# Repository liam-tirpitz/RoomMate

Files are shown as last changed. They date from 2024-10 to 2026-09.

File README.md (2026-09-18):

# RoomMate

RoomMate provides digital e-ink signs for bookable resources such as meeting rooms and offices (OfficeMate).
For meeting rooms, your RoomMate displays the current availability (occupied / available), as well as a list of upcoming meetings.
OfficeMates display up to two names and affiliations, as well as potential out-of-office notices.
This project was developed for the infrastructure at RWTH Aachen University, but is configurable to other scenarios.

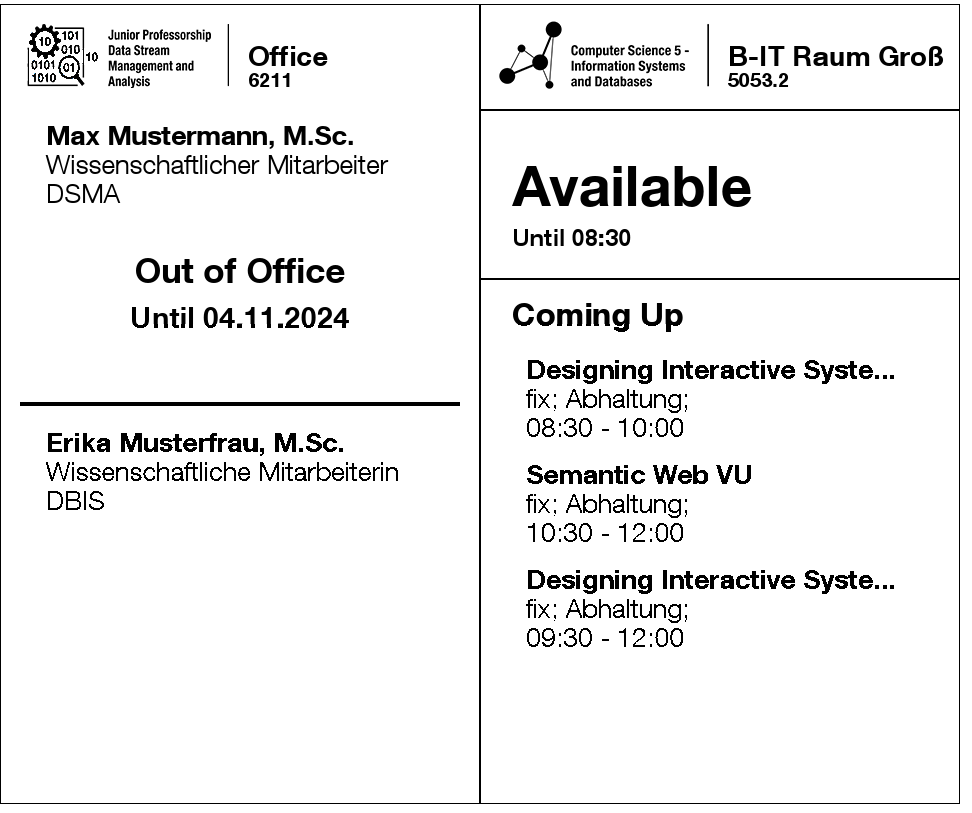
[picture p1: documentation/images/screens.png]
Screens


We currently support room calendars accessible through Microsoft Exchange and published as ical via RWTHOnline.
The calendar information is accessed through a nodejs server component.
The client consists of an eink screen and an esp32 board.
The screen content is processed on the server.
The client regularly requests the server via WiFi and HTTP and updates the screen content.

## Usage
If configured accordingly, the RoomMates for bookable rooms will automatically display the current and upcoming room occupations.
The end users can influence the content by booking the associated resources via Outlook (or RWTH Online).
The displays are battery operated.
If the battery is low and needs to be recharged, the screen will not update anymore and show a low battery warning.
In that case, the RoomMate needs to be charged via the USB-C port.

OfficeMates can be configured by the occupants of that office via their personal calendars.
Please find the details on the necessary configuration below.
If configured accordingly, Out of Office notices are automatically generated if the primary calendar of the associated user in Exchange 
contains a current appointment with  "Show as" set to "Out of Office".
The system will automatically determine the duration and display it as well.

Additionally, the occupants can configure a separate calendar "SIGN" to display custom messages.
If a custom message is set, it overwrites a potential out of office notice from the primary calendar.
For entries in "SIGN", users can set a title and the body of the message.
The message is displayed for the set duration of the appointment.
The location field is ignored.
The first 5 lines of the message body are displayed.
The title should only use 25 characters and each body line should not be longer than 45 characters.
Do not use additional HTML formatting or your message may be displayed wrong.

### Exchange Calendar Setup
If calendars are retrieved from Exchange, the system user used to access the calendars in a domain needs the permission to do so.
For different types of screens, different permissions need to be set.

#### Bookable Room Calendar
For rooms and resources, the system user needs read access to the "Full Calendar Details" (Reviewer).
These permissions can be configured by the room manager via the calendar properties in Outlook.

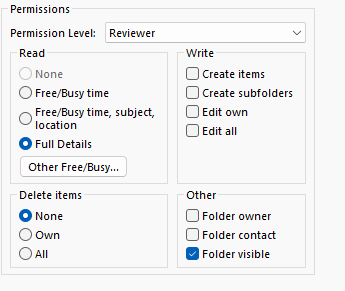
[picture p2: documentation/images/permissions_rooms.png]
Permissions


#### Personal Availability
In the case of offices, each occupant can configure their access individually.
To display Out of Office notices, the system user needs read access to the Free/Busy times.
This is often already set as the Default permission for users in the same domain, so it may not be necessary to set this explicitly.

To display custom messages, a separate calendar needs to be created and named "SIGN".
The system user needs read access to the "Full Calendar Details" (Reviewer) of the "SIGN" calendar.
Additionally, to find this calendar, the system user needs access to "Folder visible" __of the primary (parent) calendar__.

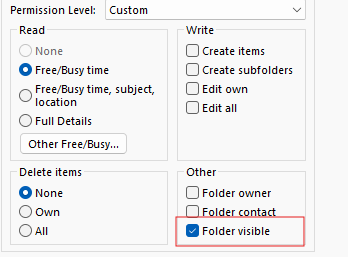
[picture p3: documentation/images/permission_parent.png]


Please note that the display of availability and out of office messages is optional. 
If the necessary permissions are not set, the display will function as a static room sign.

## Server Deployment
For an easy deployment of the server component, we recommend using our Docker image.
You can find an example on a possible docker-compose setup with that image in our [Deployment Examples](server/room-manager/deployment_example).
You can download the example and start the server with `docker compose up -d` after you changed the configuration for your needs.
The image is published as `ghcr.io/liam-tirpitz/roommate/room-manager` (`latest` for releases, `nightly` for the development branch).
The examples mount the whole [config](server/room-manager/deployment_example/config) directory, which contains `calendars.json` and the logos, to `/home/node/app/room-manager/config`, and the logs to `/home/node/app/room-manager/logs`.
Secrets can be placed in an optional `.env` file next to the `file` and `mongo` folders.

Alternatively, you can clone the repository, install node and start the server with

```bash
npm i
npm run build
npm run start
```
Make sure to pass a correct configuration and secrets.
The following environment variables are recognized:
```STORAGE``` can either be set to ```MONGO``` or ```FILE``` (default).
This determines if a MongoDB instance is expected as the storage backend or if a JSON configuration file is used.
Please note, that we currently do not support changing data via the API for the File-Backend. Write requests answer `501`.

```API_TOKEN``` enables the management API (`/rooms`, `/devices`, `/ewsusers`, `/organization`).
Requests must send it as `Authorization: Bearer <token>`.
Without it, the management API answers `403`.
The device endpoints `/data` and `/image` are always open, because devices can't authenticate.
Even with a token, only expose port 3001 to the network your devices use.
For details, please check out the [Deployment Examples](server/room-manager/deployment_example).

## Server Configuration
If a file backend is chosen, the configuration of all the rooms, persons, devices and endpoints can be done with the [calendars.json](server/room-manager/deployment_example/config/calendars.json).
For development purposes, this file should be placed inside a config directory in the root of the project.
The configuration file is loaded once when the project is started. 
If the configuration is changed, the server needs to be restarted.

### Global Configuration
`global_config` holds the settings that apply to all signs:
- `soon_threshold_in_min`: how long before a meeting a room sign shows "Next Meeting – Starts soon".
- `night_start_hour` and `night_end_hour`: signs don't update at night and wake up again at `night_end_hour`.
- `timezone`: the timezone used for all times on the signs, e.g. `Europe/Berlin`.
- `low_battery_voltage_cutoff_in_mv`: below this battery voltage, room signs show the low battery screen.
  Below 3100 mV the firmware fetches the screen one last time and then stops updating until it is charged.
  Keep this value at or above 3100 mV. Otherwise that last screen is a normal one, and the sign keeps showing outdated content without a warning.
- `default_logo`: the logo from the config directory shown on signs that are not associated with a room yet.

### Room and Device Configuration
Each room is configured with a `name` and an `id_string`, which are displayed on the screen.
In addition the affiliation of the room can be shown by using a custom logo from the config directory, indicated via `logo`.
The type of calendar is defined by either defining `ews_info` OR `ical_info` (see below).
Each device consists of a `device_id` (MAC-Address) and a descriptive `location` string.
Rooms are directly associated with the device they are configured for.
If the same room has multiple displays, the room configuration needs to be duplicated.

```json
"devices": [
    {
        "device_id": "aaaaaaaaaaaa",
        "location": "Left_Door",
        "room_id": {
            "room_number": 200,
            "id_string": "200a",
            "name": "Meetingraum",
            "logo": "institute_logo.png",
            "ews_info": {
                "email": "room@domain",
                "tenant_id": 1
            }
        }
    }
]
```

### Office Configuration
In case of offices, at most two people can be defined with independent (Exchange) calendars.
The definition of people can be set instead of an `ews_info` or `ical_info`.
Each person has a `name`, a `job` and a `group`. 
This data is displayed on the screen.
Additionally, each person has an independent `email` and `tenant_id` to retrieve their data through EWS.

```json
"persons": [
    {
        "name": "Max Mustermann, M.Sc.",
        "job": "Wissenschaftlicher Mitarbeiter",
        "group": "DSMA",
        "ews_info": {
            "email": "mustermann@institute.rwth-aachen.de",
            "tenant_id": 1
        }
    }
]
```

### Calendar Configuration
Currently, we can retrieve data from either an Exchange Server, or via ical files.

#### Exchange Configuration
To access data through the Exchange Web Services API (EWS), which is required for rooms, resources and users available in Outlook,
we need to configure access for each exchange domain.
Specifically, we need an endpoint and credentials for a user with the necessary permissions.
This user needs permissions to read the calendars for all entities that we want to map to a display.
Multiple credentials can be stored for users across domains or exchange infrastructures (`tenants`).

```json
"exchange": {
    "tenants": [
      {
        "identifier": 1,
        "endpoint": "https://ENDPOINT/EWS/Exchange.asmx",
        "user": "USER@DOMAIN",
        "secret": "SECRET"
      }
    ]
}
```

The users can then be mapped to each calendar.
Each exchange tenant requires an `endpoint`, a `user` and a password.
Through the `identifier`, exchange credentials can be mapped to a specific room or person (`tenant_id`).
The username of each calendar retrieved through exchange is configured as part of the individual calendar configuration as `email`.
```json
"calendars": [
  {
    ...
    "ews_info": {
      "email": "room@domain",
      "tenant_id": 1
    }
    
  }
]
```

We configure the endpoint and the username in the configuration file.
The passwords are injected at runtime through environment variables (`secret`).

##### Secrets
The configuration key `exchange.tenants.secret` defines the _name_ of the environment variable that is injected.

There are 3 supported ways  to inject the secrets.
First, if a Docker deployment is used is used, 
the secrets can be passed directly to the container, via the [docker-compose.yml](server/room-manager/deployment_example/file/docker-compose.yml).
For development purposes, the variables can be defined in a .env file placed in [server/](server).

Lastly, the secrets can be synchronized via [Bitwarden Secrets Manager](https://bitwarden.com/products/secrets-manager/).
In that case, we need to configure an access token in BWS and configure the environment variable `BWS_ACCESS_TOKEN`.
For this to work locally, you need to install the [Secrets Manager CLI](https://bitwarden.com/help/secrets-manager-cli/).
Local injection via the Secrets Manager can be enabled by using `npm run start_bws` or `npm run dev_bws`
The docker image already contains the CLI tool. 
To enable it, pass the `BWS_ACCESS_TOKEN` environment variable.
If this variable is not present, the secrets should be passed directly via environment variables.

#### ICal Configuration
The ical module only requires a public HTTP endpoint from which the calendar is retrieved.
__Please note, that the current ical implementation is incomplete.__
Calendars from RWTHOnline can be parsed, but more complex structures (especially recurrences) are not yet supported.

```json

"calendars": [
  {
    ...
    "ical_info": {
      "endpoint": "www.domain.de/calendar"
    }
    
  }
]
```
### Logos
We can define different logos for each device.
These logos should be placed alongside the configuration file in the config directory.
These images should be in png format and ideally already black and white. 
If they are colored, the image processing will make them black and white, but this may be less beautiful.
For the correct resolution, please check the [example](server/room-manager/deployment_example/config/institute_logo.png).

## Client

### Hardware
The hardware of the RoomMates consists of a 3D printed case and the electronics.

#### Electronics

The electronics of the RoomMates consist of the following components:
For details, see the [Bill of Material](./hardware/bom.xlsx)

- EInk-Display (7.5 inch, 800x400 black/white module with driver HAT [from Waveshare](https://www.waveshare.com/7.5inch-e-paper-hat.htm))
- ESP32-Microcontroller Development Board ([Adafruit ESP32 Feather V2](https://www.adafruit.com/product/5400))
- 3700 mAh LiPo Battery

The driver HAT connects the E-Ink display to the Microcontroller.
The Feather has built-in LiPo support and directly connects to the battery.
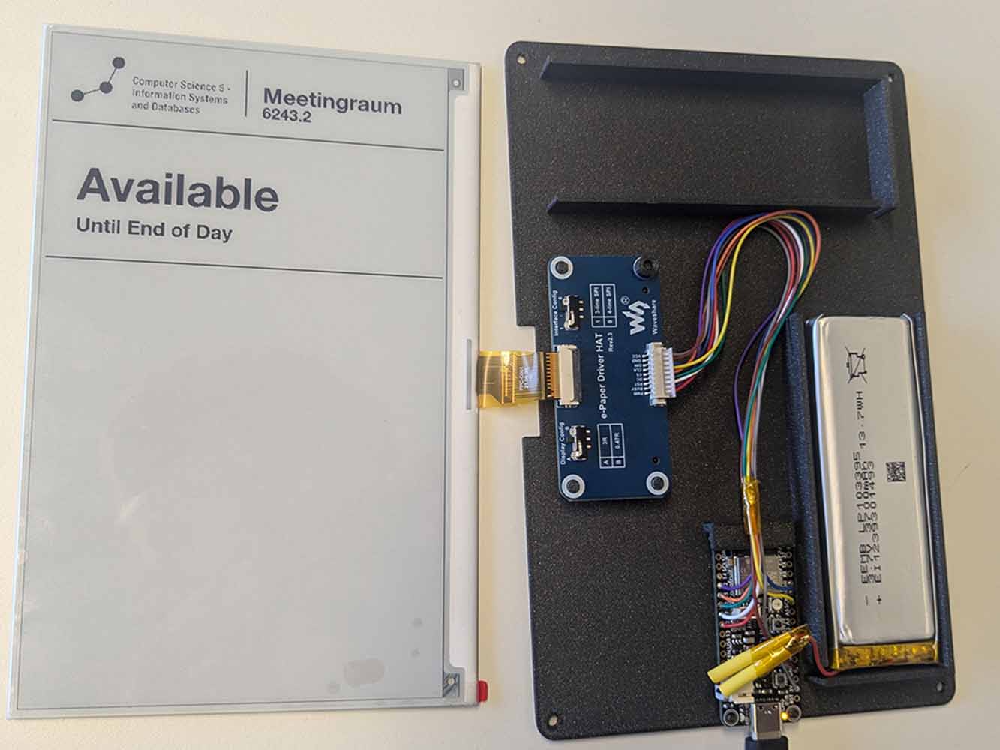
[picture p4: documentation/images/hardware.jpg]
Hardware Wiring


#### Wiring 
The e-ink HAT connector cable need to be soldered to the Feather board, according to the following pinout.
The used pins are defined in [DEV_Config.h](./client/room-occupancy/Room-Occupancy-Client/lib/esp32-waveshare-epd/src/DEV_Config.h)

| E-Ink | Feather |
|---|---|
| PWR | 12 |
| BUSY  | 32 |
| RST | 27 |
| DC | 33 |
| CS | 15 |
| CLK | 5 (SCK) |
| DIN | 19 (MOSI) |
| GND | GND |
| VCC | 3V |

#### Case
The case consists of three parts.
The front cover holds and exposes the eink display, the middle part holds the electronics and the battery and
the backplate holds everything in place and provides mounting holes for hanging the device.
The case was designed in Fusion 360.
We provide the [Fusion project files](./hardware/case/fusion_project_files) and exported [STEP files](./hardware/case/step-files).
In our deployment, we print the case on a Prusa MK4 3D printer with [Prusament PLA in Galaxy Black](https://www.prusa3d.com/de/produkt/prusament-pla-prusa-galaxy-black-1kg/).

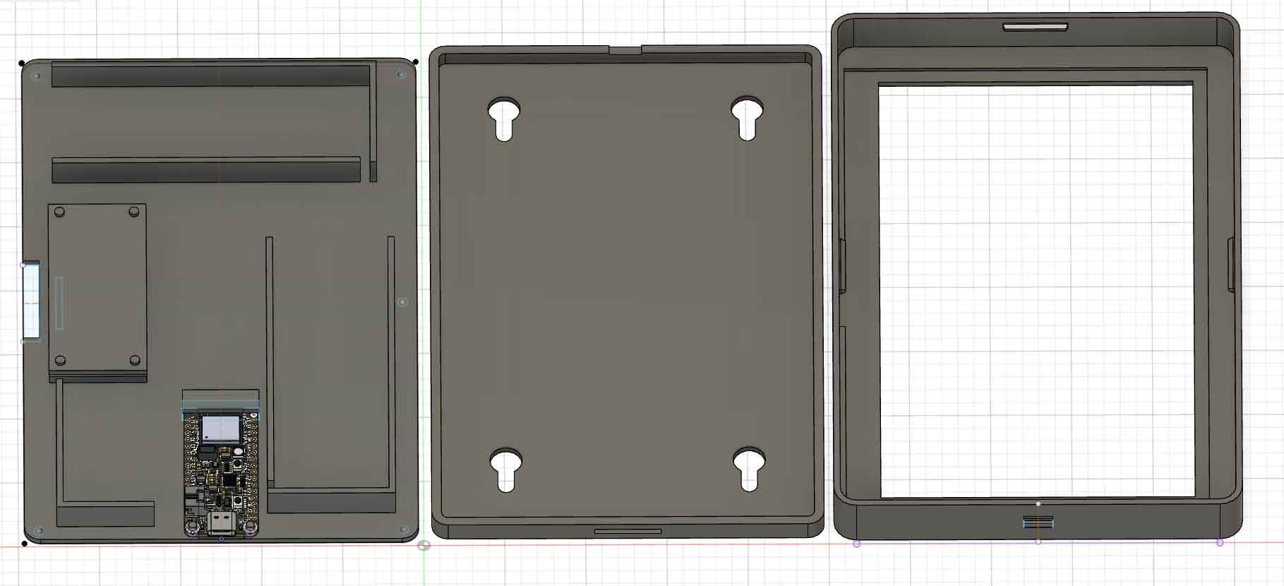
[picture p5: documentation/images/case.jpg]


### Software
The client software project is developed with [PlatformIO](https://platformio.org/) as the IDE.
The firmware of devices can be flashed via USB.

### Provisioning
To communicate with the server, each RoomMate must be provisioned with WiFi credentials and the server endpoint.
With the Provisioner [Gordon tool](server/room-manager/src/provisioner/gordon.ts) devices can be automatically provisioned, using credentials stored in the Bitwarden Secrets Manager.
For a device with the MAC address "aa:aa:aa:aa:aa:aa", place a secret of the form `PSK_aaaaaaaaaaaa` in the store.
Set `GORDON_SSID` and `GORDON_ENDPOINT` (for example `http://your-server.example.com:3001/`), run `npm run dev_gordon` and connect the RoomMates via USB.
Gordon only talks to Feather ESP32 V2 boards (USB ID `1a86:55d4`) that answer `wifi.getMAC` with a MAC address.
It provisions each connected device once and provisions it again only after it was unplugged.

Alternatively, you can manually use the the CLI via serial at a baud rate of 115200.
The following commands are needed to provision the device.

```bash
wifi.getMAC
wifi.setCredentials SSID PSK
config.setEndpoint http://SERVER:PORT/
restart
```

`config.setEndpoint` adds a missing trailing slash.
`config.setSleepInterval SECONDS` optionally changes the regular wakeup interval; it accepts values from 60 to 86400 seconds.

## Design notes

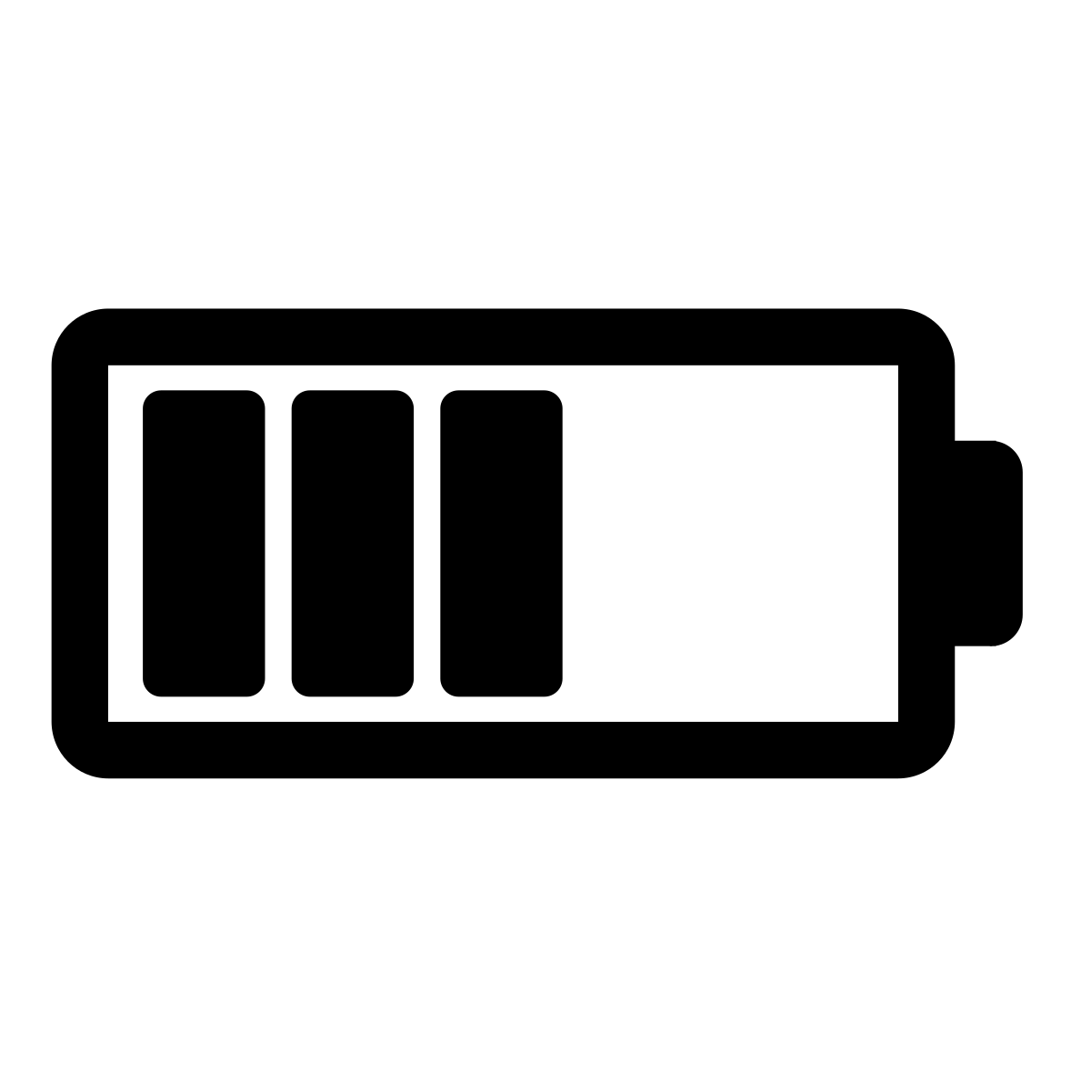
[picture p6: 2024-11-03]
server/room-manager/src/image_processing/assets/battery_3.png

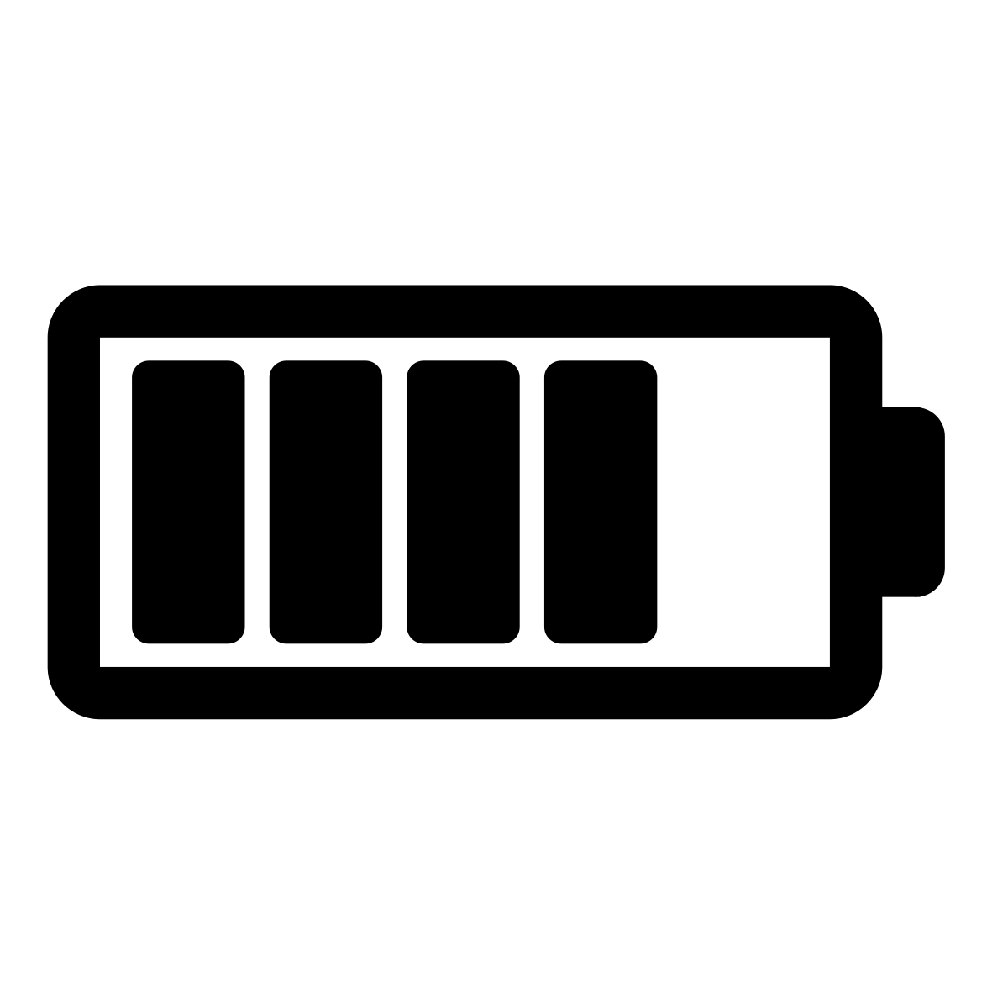
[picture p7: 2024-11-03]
server/room-manager/src/image_processing/assets/battery_4.png

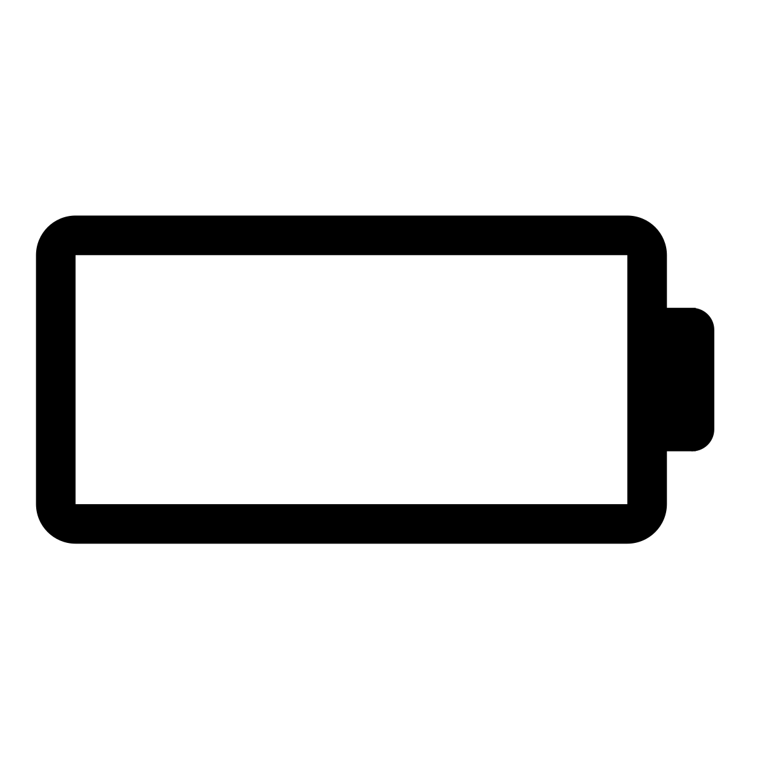
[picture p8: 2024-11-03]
server/room-manager/src/image_processing/assets/battery_0.png

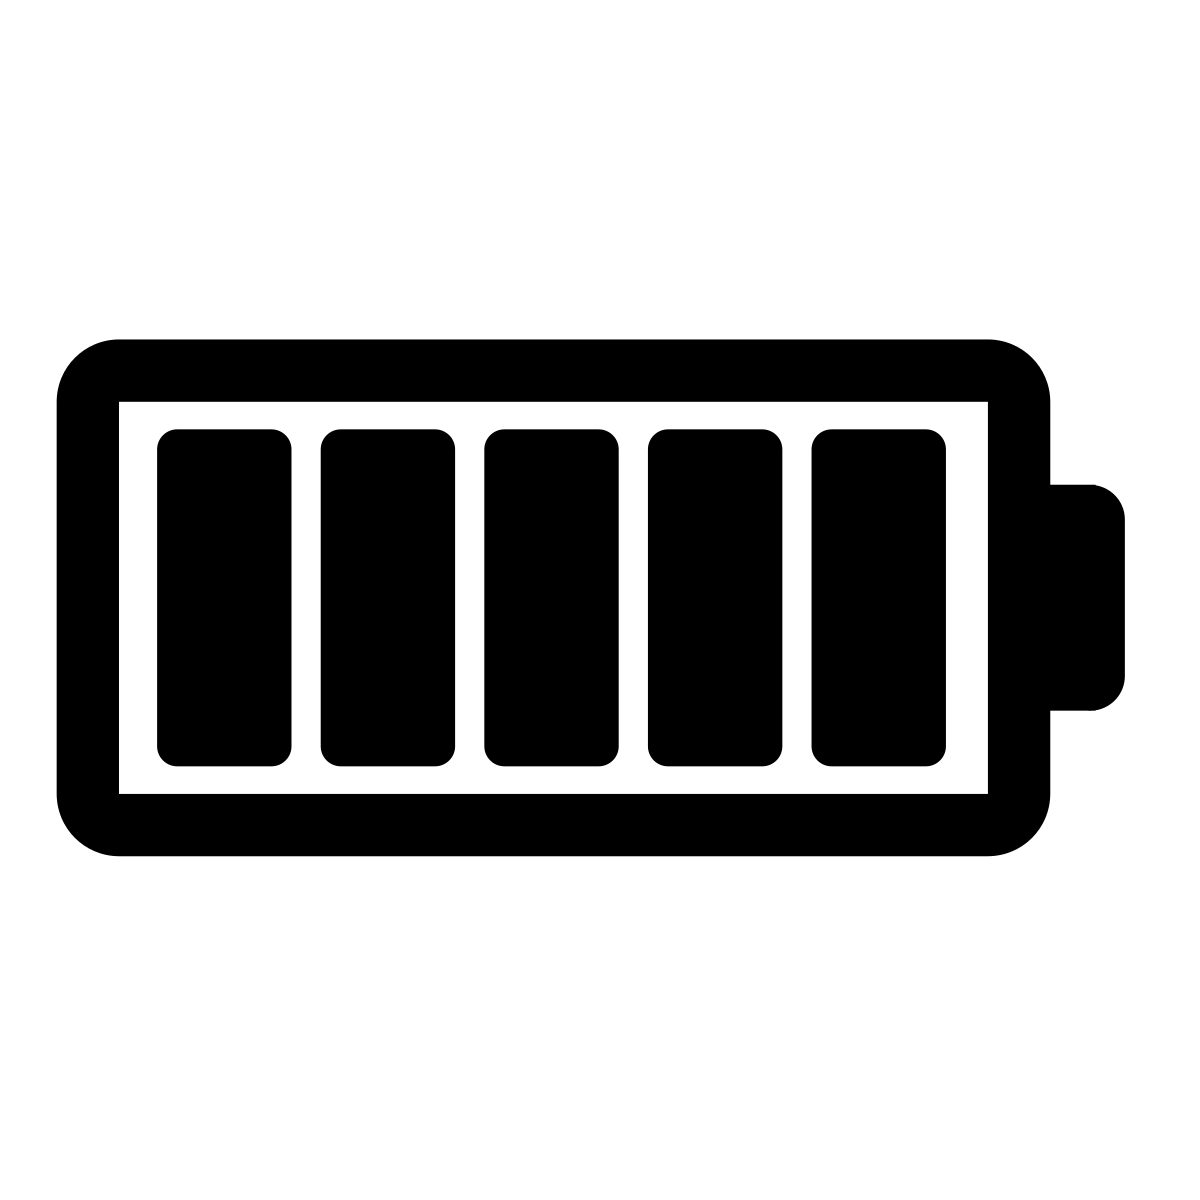
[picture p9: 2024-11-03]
server/room-manager/src/image_processing/assets/battery_5.png

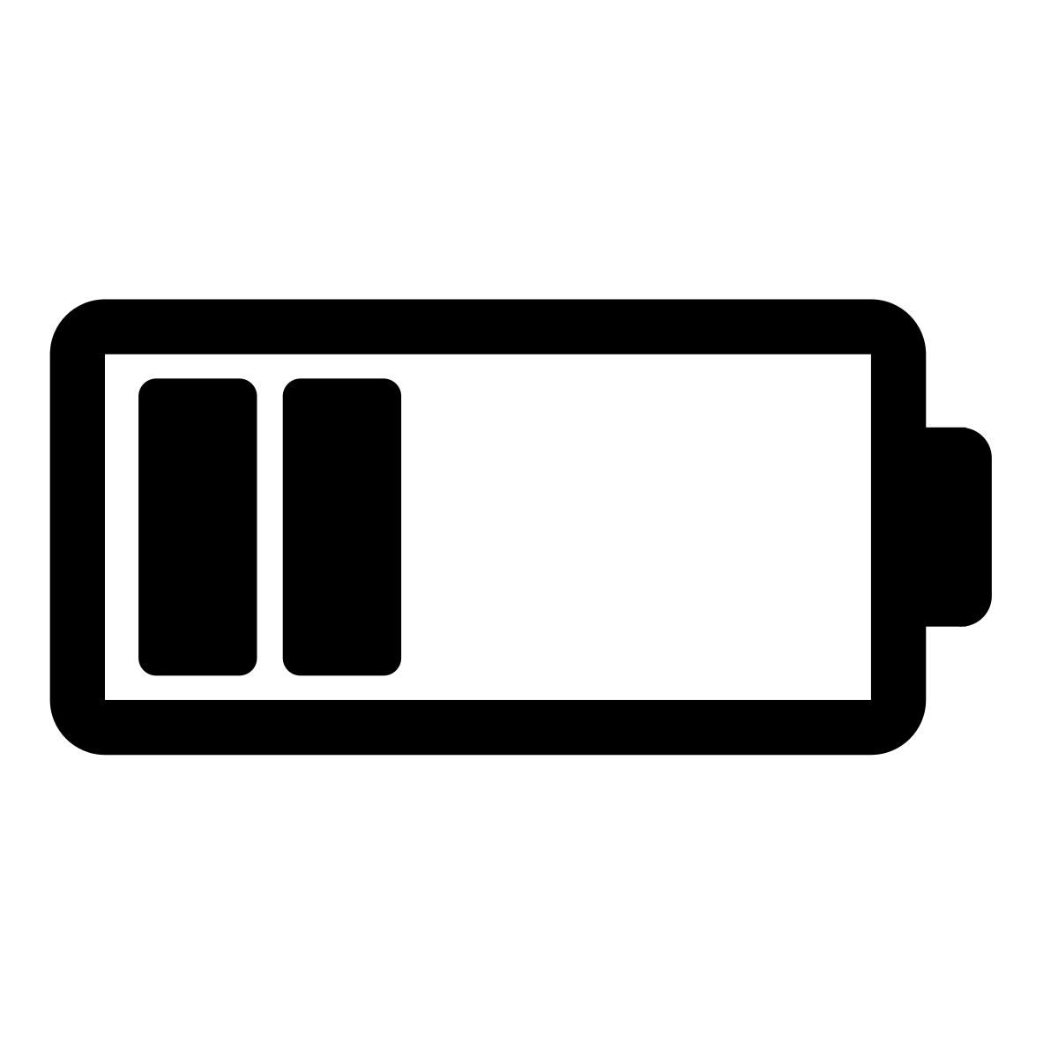
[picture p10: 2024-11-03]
server/room-manager/src/image_processing/assets/battery_2.png

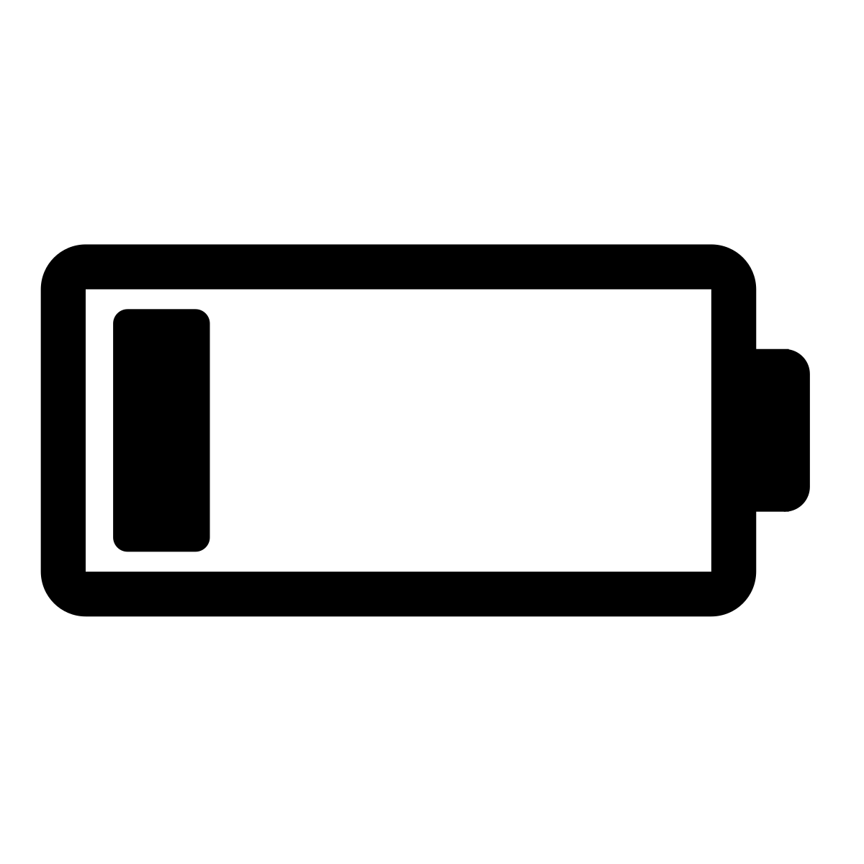
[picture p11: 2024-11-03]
server/room-manager/src/image_processing/assets/battery_1.png

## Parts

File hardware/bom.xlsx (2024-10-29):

Was |  | Preis | Stk | Kosten
EEMB LiPo 3700 mA | Akku | 13 | 2 | 26 | https://www.amazon.de/dp/B08215B4KK?ref=ppx_yo2ov_dt_b_fed_asin_title
Adafruit Feather V2 | uC | 20.3 | 1 | 20.3 | https://www.berrybase.de/adafruit-esp32-feather-v2
Waveshare 7.5 mit HAT v2 | eInk Panel | 56.9 | 1 | 56.9 | https://www.berrybase.de/7.5-800-480-epaper-display-hat-fuer-raspberry-pi-v2
 |  |  | KOSTEN | 103.2

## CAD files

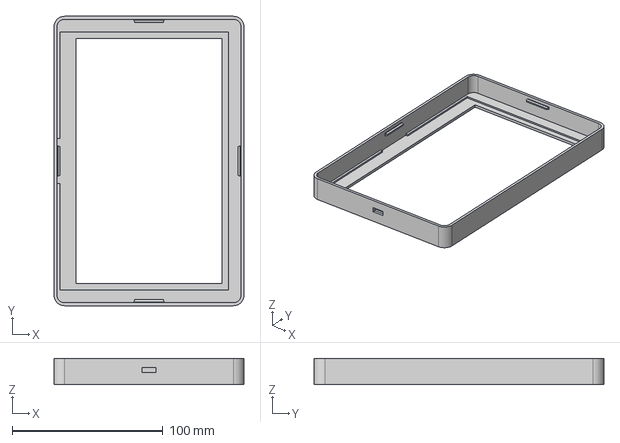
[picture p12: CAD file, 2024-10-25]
hardware/case/step-files/Front+Cover_small.stp
126.0 x 192.0 x 17.5 mm

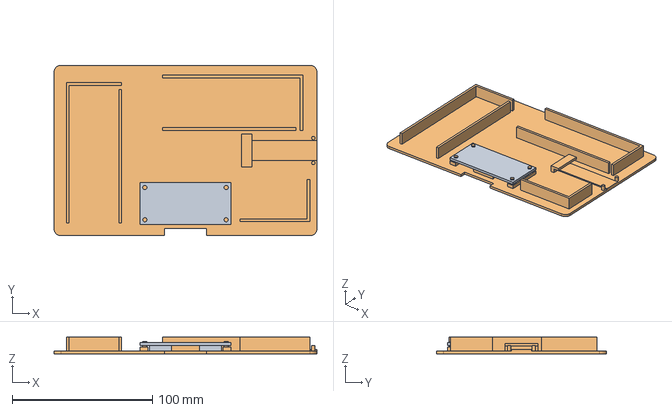
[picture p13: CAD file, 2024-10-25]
hardware/case/step-files/Gehaeuse+Mittelebene+small+feather.stp
187.5 x 121.5 x 12.0 mm

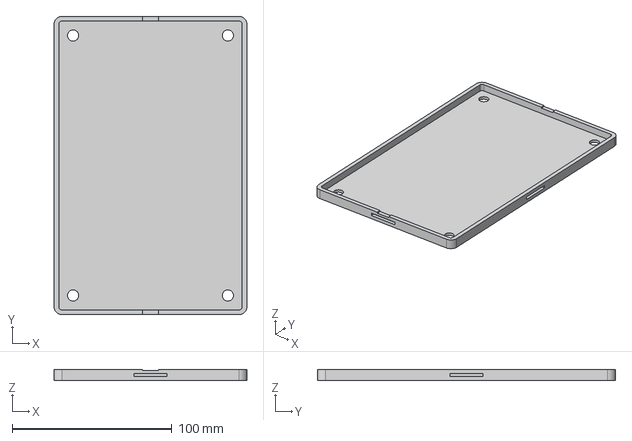
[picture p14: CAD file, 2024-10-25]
hardware/case/step-files/Backcover+small.stp
121.0 x 187.0 x 7.00 mm

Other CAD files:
hardware/case/fusion_project_files/Backcover+small.f3d
hardware/case/fusion_project_files/Front+Cover_small.f3z
hardware/case/fusion_project_files/Gehaeuse+Mittelebene+small+feather.f3z

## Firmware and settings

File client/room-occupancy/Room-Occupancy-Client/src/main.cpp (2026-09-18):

/*
 *  This sketch sends a message to a TCP server
 *
 */
#include <Arduino.h>
#include <HTTPClient.h>
#include <ArduinoJson.h>
#include <Screen.h>
#include "mbedtls/base64.h"
#include <Provisioner.h>
#include <Storage.h>
#include <SysConfig.h>
#include <ETH.h>

#define IMAGE_BUFFER_SIZE 48000
#define IMAGE_DOWNLOAD_TIMEOUT_MS 30000
// Below this voltage the radio is kept off, above the second one normal operation resumes.
// The cutoff must not be higher than low_battery_voltage_cutoff_in_mv on the server, otherwise the
// server still renders a normal screen while the device already stops updating.
#define LOW_BATTERY_CUTOFF_IN_MV 3100
#define LOW_BATTERY_RECOVERY_IN_MV 3300
#define LOW_BATTERY_SLEEP_IN_S 3600
// Time the device stays awake for serial provisioning before it goes to sleep
#define PROVISIONING_TIMEOUT_MS 600000
#define UNPROVISIONED_SLEEP_IN_S 3600
// Stored instead of a server hash while the server answers 404 for this device
#define UNKNOWN_DEVICE_HASH "unknown-device"

unsigned char b64_buff[800] = {0};
unsigned char byte_buff[IMAGE_BUFFER_SIZE] = {0};

bool eth_connection_established = false;
bool unprovisioned = false;

String devid = "";
int voltage = 0;
JsonDocument doc;


FooterState footerState;
Screen screen {&footerState};

Storage storage;
SysConfig sysconfig;


uint8_t getImageDataFromEndpoint() {
    #ifdef ARDUINO_ADAFRUIT_FEATHER_ESP32_V2
      if(WiFi.status() == WL_CONNECTED){
    #else
      if(true) {
    #endif
      HTTPClient http;
      
      String endpoint = storage.getEndpoint() + "image?devid=" + devid;
      #ifdef ARDUINO_ADAFRUIT_FEATHER_ESP32_V2
      endpoint += "&voltage=" + String(voltage);
      #endif


      http.begin(endpoint);

      int httpResponseCode = http.GET();
      size_t buffer_offset = 0;
      if (httpResponseCode>0) {
        if (httpResponseCode == HTTP_CODE_OK) {
            int len = http.getSize();
            WiFiClient *stream = http.getStreamPtr();
            // Base64 can only be decoded in complete 4-character groups, but the stream
            // delivers arbitrary chunk sizes. Up to 3 leftover characters are carried
            // over to the front of b64_buff and decoded together with the next chunk.
            size_t carry = 0;
            bool decode_failed = false;
            unsigned long download_start = millis();
            while (http.connected() && (len > 0 || len == -1)) {
              if (millis() - download_start > IMAGE_DOWNLOAD_TIMEOUT_MS) {
                printf("Image download timed out\n");
                decode_failed = true;
                break;
              }
              size_t size = stream->available();
              if (size) {
                size_t space = sizeof(b64_buff) - carry;
                int c = stream->readBytes(b64_buff + carry, (size > space) ? space : size);
                if (len > 0) {
                  len -= c;
                }
                size_t available_chars = carry + c;
                size_t decodable_chars = available_chars - (available_chars % 4);
                if (decodable_chars > 0) {
                  size_t outlen = 0;
                  int decode = mbedtls_base64_decode(byte_buff + buffer_offset, IMAGE_BUFFER_SIZE - buffer_offset,
                                                     &outlen, b64_buff, decodable_chars);
                  if (decode != 0) {
                    printf("Base64 decode failed: %d at offset %u\n", decode, (unsigned) buffer_offset);
                    decode_failed = true;
                    break;
                  }
                  buffer_offset += outlen;
                }
                carry = available_chars - decodable_chars;
                memmove(b64_buff, b64_buff + decodable_chars, carry);
              } else {
                delay(1);
              }
            }

          http.end();
          if (decode_failed || carry != 0 || buffer_offset != IMAGE_BUFFER_SIZE) {
            printf("Incomplete image: %u of %d bytes\n", (unsigned) buffer_offset, IMAGE_BUFFER_SIZE);
            return 4;
          }
          return 0;
        }
      }
      else {
        // Serial.print("Error code: ");
        // Serial.println(httpResponseCode);
        http.end();
        return 1;
      }
      // Free resources
    }
    else {
      printf("WiFi Disconnected\n");
      return 2;
    }
    return 3;
}

bool getMetaDataFromEndpoint() {
  bool success = false;
  #ifdef ARDUINO_ADAFRUIT_FEATHER_ESP32_V2
  if(WiFi.status() == WL_CONNECTED){
  #else
  if(true) {
  #endif
    HTTPClient http;
    http.begin(storage.getEndpoint() + "data?devid=" + devid);
    printf("BEGIN\n");
    int httpResponseCode = http.GET();
    if (httpResponseCode>0) {
      if (httpResponseCode == HTTP_CODE_OK) {
        String payload = http.getString();
        DeserializationError error = deserializeJson(doc, payload);
        if (error) {
          // Serial.print(F("deserializeJson() failed: "));
          // Serial.println(error.f_str());
          printf("%s \n", payload.c_str());

       } else {
          printf("Retrieved Metadata\n");
          success = true;
       }
      } else if (httpResponseCode == HTTP_CODE_NOT_FOUND
                 && !deserializeJson(doc, http.getString()) && doc["error"].is<const char*>()) {
        // The server does not know this device. Its image endpoint still serves the "new device" screen
        // with the MAC, so draw that once under a fixed hash and check again at the regular interval.
        printf("Device not registered on the server.\n");
        doc.clear();
        doc["hash"] = UNKNOWN_DEVICE_HASH;
        success = true;
      } else {
        printf("Connection failed: %d\n", httpResponseCode);
      }
    }
    printf("Close connection\n");
    http.end();
  }
  return success;
}

void configureSleep(long sleep_time_in_s) {
    // A wakeup time in the past would wrap around to an unpredictable, potentially very long sleep
    if (sleep_time_in_s <= 0) {
      printf("Invalid sleep time %ld s, falling back to the regular interval.\n", sleep_time_in_s);
      sleep_time_in_s = storage.getRegularSleepTimeInS();
    }
    // The stored interval is not validated either, so clamp here as well
    if (sleep_time_in_s < MIN_SLEEP_TIME_IN_S) {
      sleep_time_in_s = MIN_SLEEP_TIME_IN_S;
    }
    if (sleep_time_in_s > MAX_SLEEP_TIME_IN_S) {
      sleep_time_in_s = MAX_SLEEP_TIME_IN_S;
    }
    esp_sleep_enable_timer_wakeup((uint64_t) sleep_time_in_s * uS_TO_S_FACTOR);
    printf("Sleep configured for %ld s.\n", sleep_time_in_s);
}

// Returns whether the screen is known to show the current content
bool handleMetadata() {
  long next_update_unix = doc["next_update_unix"]; // 1728220858
  const char* hash = doc["hash"]; // "d41d8cd98f00b204e9800998ecf8427e"
  long current_time_unix = doc["current_time_unix"]; // 1728220858
  bool is_night = doc["is_night"]; // false
  bool is_weekend = doc["is_weekend"]; // false
  // Without valid metadata there is nothing to draw and nothing to schedule. Sleeping regularly here
  // avoids a reboot loop that would drain the battery while the server is unreachable.
  bool needs_update = hash != nullptr && storage.checkHash(hash);
  if (hash == nullptr) {
    printf("No metadata available.\n");
  }
  bool up_to_date = hash != nullptr;
  // Redraw screen if metadata changed
  if (needs_update) {
    printf("Update required.\n");
    up_to_date = false;
    if(!getImageDataFromEndpoint()) {
        screen.setup();
        screen.drawImage(byte_buff);
        screen.sleep();
        // Only remember the hash after a successful draw, so a failed download is retried on the next wakeup
        storage.setHash(hash);
        up_to_date = true;
    }
  } else {
      printf("Im Westen nichts neues.\n");
  }
  storage.getPreferences().end();
  // Serial.println("Configure sleep.");

  #ifdef ARDUINO_ADAFRUIT_FEATHER_ESP32_V2

    long diff = next_update_unix - current_time_unix;
    long sleep_time_in_s = 0;
    int regular_wakeup_interval_in_s = storage.getRegularSleepTimeInS();
    if (
        next_update_unix > 0
        && diff > 0
        // Skip next regular update if next event is less than 10 minutes in the future
        && ((diff < regular_wakeup_interval_in_s) || (diff - regular_wakeup_interval_in_s) < 600)) {
      sleep_time_in_s = diff + 30;
    } else if ((is_night || is_weekend) && next_update_unix > 0 && diff > 0) {
      sleep_time_in_s = diff + 30;
    } else {
      sleep_time_in_s = regular_wakeup_interval_in_s;
    }
    configureSleep(sleep_time_in_s);
  #endif
  return up_to_date;
  //printf("Wait for ");
  // Serial.print(sleep_time_in_s);
  // Serial.println();

}


bool updateState() {
    getMetaDataFromEndpoint();
    return handleMetadata();
}


// Actually, those are Ethernet Events.
void ETHEvent(WiFiEvent_t event)
{

  switch (event) {

    case ARDUINO_EVENT_ETH_START:
      // This will happen during setup, when the Ethernet service starts
      printf("ETH Started\n");
      //set eth hostname here
      // ETH.setHostname("esp32-ethernet");
      eth_connection_established = false;

      break;

    case ARDUINO_EVENT_ETH_CONNECTED:
      // This will happen when the Ethernet cable is plugged 
      printf("ETH Connected\n");
      break;

    case ARDUINO_EVENT_ETH_GOT_IP:
    // This will happen when we obtain an IP address through DHCP:
      devid = ETH.macAddress();
      devid.replace(":","");  
      printf("Got an IP Address for ETH MAC. \n");
      // Serial.print(ETH.macAddress());
      // Serial.print(", IPv4: ");
      // Serial.print(ETH.localIP());
      // if (ETH.fullDuplex()) {
      //   Serial.print(", FULL_DUPLEX");
      // }
      // Serial.print(", ");
      // Serial.print(ETH.linkSpeed());
      // Serial.println("Mbps");
      eth_connection_established = true;
      break;

    case ARDUINO_EVENT_ETH_DISCONNECTED:
      // This will happen when the Ethernet cable is unplugged 
      printf("ETH Disconnected\n");
      eth_connection_established = false;

      break;

    case ARDUINO_EVENT_ETH_STOP:
      // This will happen when the ETH interface is stopped but this never happens
      printf("ETH Stopped\n");
      break;

    default:
      break;
  }
}



void setup() {
    Provisioner p = Provisioner();
    #ifdef ARDUINO_ADAFRUIT_FEATHER_ESP32_V2
      devid = WiFi.macAddress();
      sysconfig.configDefaultSleep();
      if(storage.getEndpoint() != "" && storage.getSSID() != "" && storage.getPSK() != "")  {
          devid.replace(":","");
          voltage = sysconfig.readBatteryVoltage();
          printf("Battery: %d mV\n", voltage);
          // Stay in low battery mode until the battery is charged well above the cutoff, otherwise a
          // voltage hovering around it would alternate between the warning and normal updates.
          if (voltage > 0 && (voltage < LOW_BATTERY_CUTOFF_IN_MV
                              || (storage.getLowBatteryShown() && voltage < LOW_BATTERY_RECOVERY_IN_MV))) {
              // Arm the low battery interval before the radio is powered, because a failed WiFi
              // connection sleeps immediately and would otherwise use the regular interval
              configureSleep(LOW_BATTERY_SLEEP_IN_S);
              // Fetch the low battery screen once, then keep the radio off until the device is charged again.
              // Waking up regularly on an empty battery drains it further and risks brownout reboots.
              if (!storage.getLowBatteryShown()) {
                  // The warning replaces the current content, so it has to be drawn even though the
                  // calendar data itself did not change
                  storage.invalidateHash();
                  sysconfig.setup_wifi_connection();
                  // Only stop updating once the warning is actually on the screen
                  if (updateState()) {
                      storage.setLowBatteryShown(true);
                  }
              } else {
                  printf("Battery still low, skipping update.\n");
              }
              // updateState() configures the sleep time from the metadata, so set it again
              configureSleep(LOW_BATTERY_SLEEP_IN_S);
              sysconfig.sleep();
          }
          if (storage.getLowBatteryShown()) {
              printf("Battery charged, resuming normal operation.\n");
              storage.setLowBatteryShown(false);
              // The screen still shows the warning and has to be replaced
              storage.invalidateHash();
          }
          // Serial.println(devid);
          sysconfig.setup_wifi_connection();
          updateState();
          sysconfig.sleep();
      } else {
        screen.setup();
        screen.drawNewDeviceImage(devid.c_str());
        screen.sleep();
        // Stay awake for configuration if config is incomplete, see loop()
        unprovisioned = true;
      }

    #else
      WiFi.onEvent(ETHEvent);
      ETH.begin();

    #endif 

}


void loop() {
  #ifdef ARDUINO_ADAFRUIT_FEATHER_ESP32_V2
      if(unprovisioned) {
        // The console runs in its own task, so pick up a configuration as soon as it is complete
        if(storage.getEndpoint() != "" && storage.getSSID() != "" && storage.getPSK() != "") {
          printf("Configuration received, restarting.\n");
          ESP.restart();
        }
        // Do not stay awake forever waiting for a serial configuration that may never come
        if(millis() > PROVISIONING_TIMEOUT_MS) {
          printf("No configuration received, going to sleep.\n");
          configureSleep(UNPROVISIONED_SLEEP_IN_S);
          sysconfig.sleep();
        }
        delay(500);
      }
  #else
      if(eth_connection_established) {
        updateState();
        delay(60000);
      }
  #endif
}

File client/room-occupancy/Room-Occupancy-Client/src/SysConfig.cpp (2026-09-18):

#include <SysConfig.h>


SysConfig::SysConfig() {
};

void SysConfig::sleep() {
    esp_sleep_pd_config(ESP_PD_DOMAIN_RTC_PERIPH,   ESP_PD_OPTION_OFF);
    esp_sleep_pd_config(ESP_PD_DOMAIN_RTC_SLOW_MEM, ESP_PD_OPTION_OFF);
    esp_sleep_pd_config(ESP_PD_DOMAIN_RTC_FAST_MEM, ESP_PD_OPTION_OFF);
    esp_sleep_pd_config(ESP_PD_DOMAIN_XTAL,         ESP_PD_OPTION_OFF);
    esp_deep_sleep_start();
}

void SysConfig::configDefaultSleep() {
    esp_sleep_enable_timer_wakeup(storage.getRegularSleepTimeInS() * uS_TO_S_FACTOR);
}

int SysConfig::readBatteryVoltage() {
    #ifdef ARDUINO_ADAFRUIT_FEATHER_ESP32_V2
    float measuredvbat = analogReadMilliVolts(VBATPIN);  
    measuredvbat *= 2;    
    int milivolt = round(measuredvbat);
    return milivolt;
    #else
    return 0;
    #endif 
}

void SysConfig::setup_wifi_connection() {
  WiFi.mode(WIFI_STA);
  WiFi.begin(storage.getSSID().c_str(), storage.getPSK().c_str());

  // Serial.println();
  // Serial.println();
  printf("Waiting for WiFi... ");
  unsigned long connect_start = millis();
  while (WiFi.status() != WL_CONNECTED && (millis() - connect_start) < WIFI_CONNECT_TIMEOUT_MS) {
    printf(".");
    delay(250);
  }

  // Do not stay awake with the radio on if the network is unavailable
  if (WiFi.status() != WL_CONNECTED) {
      printf("Could not connect to WiFi... ");
      sleep();
  }

  // Serial.println("");
  printf("WiFi connected");
  // Serial.println("IP address: ");
  // Serial.println(WiFi.localIP());
}

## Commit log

2024-09-27 Switch to Platformio
2024-09-28 Init eInk Driver
2024-09-28 Generate Image Header and CurrentEvent Details. Towards #4
2024-09-29 CurrentEvent Details from class data. Towards #4
2024-09-30 Dynamically generate current room occupation
2024-10-01 case fix in library
2024-10-03 Partially working generation of live data (with crashes and artefacts)
    [main.cpp]
2024-10-09 Update Day-Rollover for correct wakeup of devices in the morning
2024-10-10 Draw free-box bigger than frame to avoid right border line.
2024-10-19 Fix bug in nvs access
    [main.cpp]
2024-10-23 Add feather to devices list
2024-10-25 Add case files
    [Backcover+small.f3d, Backcover+small.stp, Front+Cover_small.f3z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]
2024-10-27 Determine longest valid out-of-office entry that is currently in effect for each person in an office
2024-10-28 Added bill of material
    [bom.xlsx]
2024-10-29 Generate data for office type
    [bom.xlsx]
2024-10-29 receive battery voltage and draw Low Battery-warning
2024-10-29 Update logs to include voltage
2024-10-29 Add init prompt screen for unknown device
2024-11-02 Add Voltage reading and send to server
2024-11-02 Update provisioning stage screens
2024-11-03 Add screen for uninitialized device
2024-11-03 Show last update and battery state as server-side footer.
2024-11-17 dev(server): Add Devices Endpoint
2024-11-18 dev(server): Add endpoint for ews data and populate for device retrieval
2024-11-23 feat(server): Make File-Backend and Mongo Backend Switchable through environment variable.
2025-03-08 Hack to improve stability with regard to drawing mistakes
    [main.cpp]
2025-03-09 fix(server): Exclude current time from hash
2025-09-01 dev(server): Fixes bug in office calendars when there is no current busy event
2026-09-17 fix(client): Decode image download in complete base64 groups Partial base64 groups at read boundaries were dropped, which tore the image on slow WiFi.
    [main.cpp]
2026-09-18 fix(client): Prevent battery drain from invalid sleep times and failed requests
    [SysConfig.cpp, main.cpp]
2026-09-18 fix(client): Correct low battery handling and sleep bounds
    [main.cpp]
2026-09-18 fix(client): Use the correct HTTPClient.h header name
    [main.cpp]
2026-09-18 fix(server): Mount config and logs at the paths the container reads
2026-09-18 fix(server): Answer 404 for unknown devices instead of failing
    getData read room_id of an undefined device and the request failed with 500. Both state endpoints set a 404 status but then sent 200 with a plain-text body.
2026-09-18 fix(server): Skip ended iCal events so the status box shows the current state
    The iCal feed contains the whole day. An event that had already ended became data[0], so the status box stayed empty and past meetings appeared under Coming Up.
2026-09-18 test(server): Add tests for unknown devices, iCal filtering and the daily hash
    Tests are written in TypeScript and run with tsx, so CI does not need a build first.
2026-09-18 fix(server): Dither the rendered screen so grey areas keep their shading
    finalizeImage dithered a 480x800 region of the already rotated 800x480 canvas in binary mode, which matched the later threshold exactly, so dithering changed no pixels. It now dithers the canvas at its current size with Atkinson dithering.
    Also fixes the loops that read one pixel past the end of the image data, and rounds diffused errors towards zero. Flooring left a -1 residue that never decayed and drew diagonal streaks across white areas.
2026-09-18 fix(server): Require an API token for the management API
    /rooms, /devices, /ewsusers and /organization accepted reads, writes and deletes from anyone who could reach port 3001, and /ewsusers exposed the Exchange endpoints and user names. They now require a bearer token from API_TOKEN and are disabled without it. The device endpoints stay open.
    Writes on the file backend were silently ignored and now answer 501.
2026-09-18 fix(server): Only provision RoomMates with Gordon and read SSID and endpoint from the environment
    Gordon opened every serial port every 5 seconds and sent the WiFi credentials to anything that answered. It now only opens Feather ESP32 V2 ports, provisions a device only after it reports a MAC address, and handles each connected device once.
    Commands use a single listener with a timeout instead of adding a listener per command, and the port is closed after the restart command. The SSID and endpoint come from GORDON_SSID and GORDON_ENDPOINT instead of being hardcoded.
2026-09-18 docs: Fix the tenant field and provisioning command, document global_config
    The README called the tenant field id instead of identifier, the room name field tenants instead of name, and the command wiFi.setCredentials instead of wifi.setCredentials. It now documents global_config, the endpoint slash handling, the sleep interval range and how the server's low battery cutoff relates to the firmware's.
2026-09-18 fix(client): Show the new device screen when the server does not know the device
    The server answers /data with 404 for unregistered devices. The firmware treated that as missing metadata and never requested /image, so the sign never showed the new device screen with its MAC. A 404 with a JSON error now draws that screen once under a fixed hash. The device keeps checking at the regular interval and redraws once it is registered.
    [main.cpp]
2026-09-18 fix(server): Give the example office a room_number so the server recognises it
    The office device in the example config used id instead of room_number. isRoom() checks for room_number, so the server treated the device as unknown and showed the new device screen instead of the office sign. The Docker image ships this config, and CI uses it too.
